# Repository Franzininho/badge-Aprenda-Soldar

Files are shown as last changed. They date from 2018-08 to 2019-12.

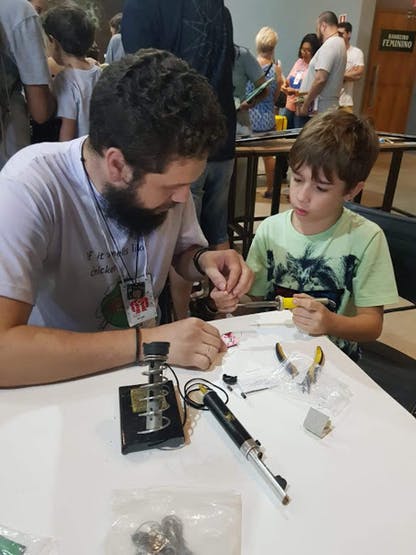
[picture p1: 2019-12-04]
img/05.jpg

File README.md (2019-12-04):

# Badge - Aprenda Soldar

O badge Aprenda Soldar foi desenvolvido para oficinas de solda onde os participantes dão os primeiros passos com o uso de ferramentas e no conhecimento dos componentes eletrônicos e circuito da placa. Com poucos componentes, esse badge permite que qualquer pessoa aprenda a soldar e se divertir.

O circuito escolhido para esse badge, foi o clássico multivibrador astável com trasistores.

A placa foi desenhada no [Kicad](https://kicad-pcb.org/) e os arquivos estão disponíveis no github. A placa possui duas camadas e necessita de metalização de furos para acabamento.

A seguir é apresentada a lista de materiais:

- 2 x Resistor 470k
- 2 x Resistor 470 Ohm
- 2 x transistor BC548
- 1x LED 3mm verde
- 1x LED 3mm amarelo
- 2 x Capacitor 10uF x 16V
- 1 x Suporte para bateria CR2032
- 1 x Bateria CR2032

Esse projeto foi um dos vencedores do [Contest badge Love](https://www.hackster.io/contests/BadgeLove) na categoria The Badge of Hope, promovido pelo [Hackster](https://www.hackster.io/fabiosouza/badge-aprenda-soldar-learn-to-solder-1f082d)

O projeto é open hardware e foi publicado sob a licença [Creative Commons Attribution Share Alike 4.0 International](https://github.com/Open-Badges/badge00/blob/master/LICENSE)

Esse projeto faz parte da família de placas Franzininho e foi desenvolvido por Fábio Souza, idealizador do projeto. Para mais detalhes acesse o site da [Franzininho](https://franzininho.com.br/)

Para adquirir placas e kits do badge Aprenda Soldar, entre em contato conosco: [contato@franzininho.com.br](contato@franzininho.com.br)

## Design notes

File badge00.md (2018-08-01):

## Badge00 - Aprenda Soldar

O Badge00 foi desenvolvido para oficinas de solda onde os participantes dão os primeiros passos com o uso de ferramentas e o conhecimento dos componentes.

O circuito escolhido para esse badge, foi o clássico multivibrador astável com trasistores.

### Placa



A placa foi desenhada no Kicad e os arquivos estão disponíveis no github. A placa foi desenhada em duas camadas e necessita de metalização de furos para acabamento.

### Circuito



O circuito..

### Lista de componentes

## Montagem

Para montagem, primeiramente é necessário preparar as ferramentas. Para a realização da soldagem do Badge00 você irá precisar das seguintes ferramentas e insumos:
- Ferro de solda 30 W
- Suporte para Ferro de solda
- Alicate de corte diagonal
- Estanho
- Sugador de solda (opcional)
- Suporte  para soldagem (terceira mão)(opcional)

Separe os componentes de forma organizada na sua bancada.

Verifique se o ferro de solda está aquecido e pronto para a soldagem.

Insira os resistores na placa:
- R1 - 470 R
- R2 - 47 K
- R3 - 47 K
- R4 - 470 R

Fique atento ao código de cores. Após inserir os resistores na placa, vire com cuidado para que os resistores não caiam e então, solde-os:

Com os resistores soldados, vamos soldar os transistores:

Q1 e Q2 = BC548(ou similar)

Encaixe os transistores em suas respectivas posições, vire a placa e solde-os:

Agora vamos soldar os capacitores eletrolíticos:

C1 e C2 = 10 uF x  25V

Para inserir os capacitores na placa é importante verificar a polaridade. Com os capacitores encaixados corretamente, vire a placa e sode os mesmos. Tome cuidado para que os mesmos fiquem apoiados a placas e não fiquem altos.

O próximo passo é a soldagem dos LEDs. Os LEDs dever ser soldados no lado do Robô. Encaixe os LEDs respeitando a polaridade. Vire a placa e solde os mesmos. Cuidados para que os LEDs não fiquem altos ou desalinhados.

Por ultimo, vamos soldar o suporte de baterias. Encaixe-o na placa e solde-o:

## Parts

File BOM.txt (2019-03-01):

Ref		Descrição									Quatidade
placa	Placa Badge00									1
Q1,Q2	Transistor BC548								2
C1, C2	Capacitor Eletrolítico 10uF x 25 V				2
R1,r4	Resistor 470R									2
R2,R3	Resistor 47K									2
BT1		Suporte de bateria CR2032						1
BT1		Bateria CR2032									1
LED1	Led Amarelo 3mm									1
LED2	LED Verde 3mm									1
S1		Chave HH - SS12D07								1

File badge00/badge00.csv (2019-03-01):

Id | Designator | Package | Quantity | Designation | Supplier and ref
1 | BT1 | CR2032_HOLDER | 1 | Battery_Cell
2 | R1,R4 | R_Axial_DIN0207_L6.3mm_D2.5mm_P10.16mm_Horizontal | 2 | 470R
3 | REF** | MountingHole_3.5mm | 1 | MountingHole_3.5mm
4 | C1,C2 | CP_Radial_D5.0mm_P2.50mm | 2 | 10uF
5 | D1,D2 | LED_D3.0mm | 2 | LED
6 | R2,R3 | R_Axial_DIN0207_L6.3mm_D2.5mm_P10.16mm_Horizontal | 2 | 47k
7 | Q1,Q2 | TO-92_Inline_Wide | 2 | BC548
8 | G*** | robot2_35x35 | 1 | LOGO
9 | G*** | logo-franzininho12_7 | 1 | LOGO
10 | SW1 | SW_HH_SS12D07-G4-2 | 1 | SW_SPDT
11 | REF*** | OSHW-Logo_7.5x8mm_SilkScreen | 1 | OSHW-Logo_7.5x8mm_SilkScreen
12 | REF*** | KiCad-Logo2_6mm_SilkScreen | 1 | KiCad-Logo2_6mm_SilkScreen

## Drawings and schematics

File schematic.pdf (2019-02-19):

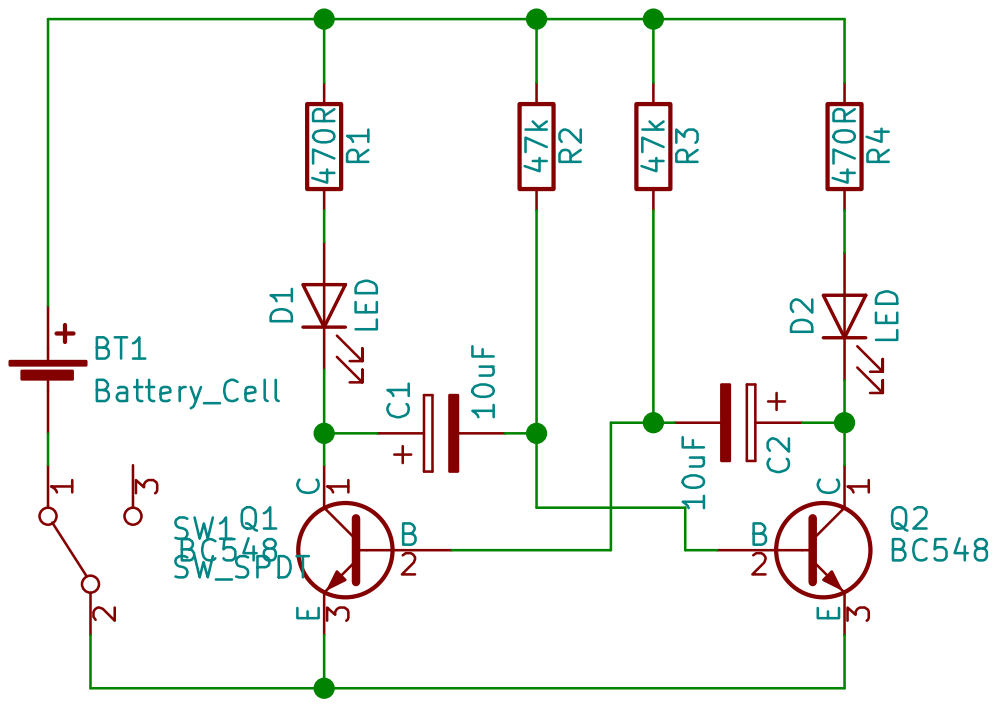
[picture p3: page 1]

File: badge00.sch Sheet: / Franzininho

Id: 1/1 Title: Badge - Aprenda Soldar

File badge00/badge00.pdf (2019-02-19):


File: badge00.sch Sheet: / Franzininho

Id: 1/1 Title: Badge - Aprenda Soldar

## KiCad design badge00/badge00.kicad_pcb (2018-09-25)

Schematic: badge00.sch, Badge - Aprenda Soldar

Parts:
BT1: Battery_Cell; CR2032_HOLDER
C1, C2: 10uF; CP_Radial_D5.0mm_P2.50mm
D1, D2: LED; LED_D3.0mm
Q1, Q2: BC548; TO-92_Inline_Wide
R1, R4: 470R; R_Axial_DIN0207_L6.3mm_D2.5mm_P10.16mm_Horizontal
R2, R3: 47k; R_Axial_DIN0207_L6.3mm_D2.5mm_P10.16mm_Horizontal
SW1: SW_SPDT; SW_HH_SS12D07-G4-2

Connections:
unnamed: BT1.1, R1.1, R2.1, R3.1, R4.1
unnamed: BT1.2, SW1.1
unnamed: C1.1, D1.1, Q1.1 (C)
unnamed: C1.2, Q2.2 (B), R2.2
unnamed: C2.1, D2.1, Q2.1 (C)
unnamed: C2.2, Q1.2 (B), R3.2
unnamed: D1.2, R1.2
unnamed: D2.2, R4.2
unnamed: Q1.3 (E), Q2.3 (E), SW1.2

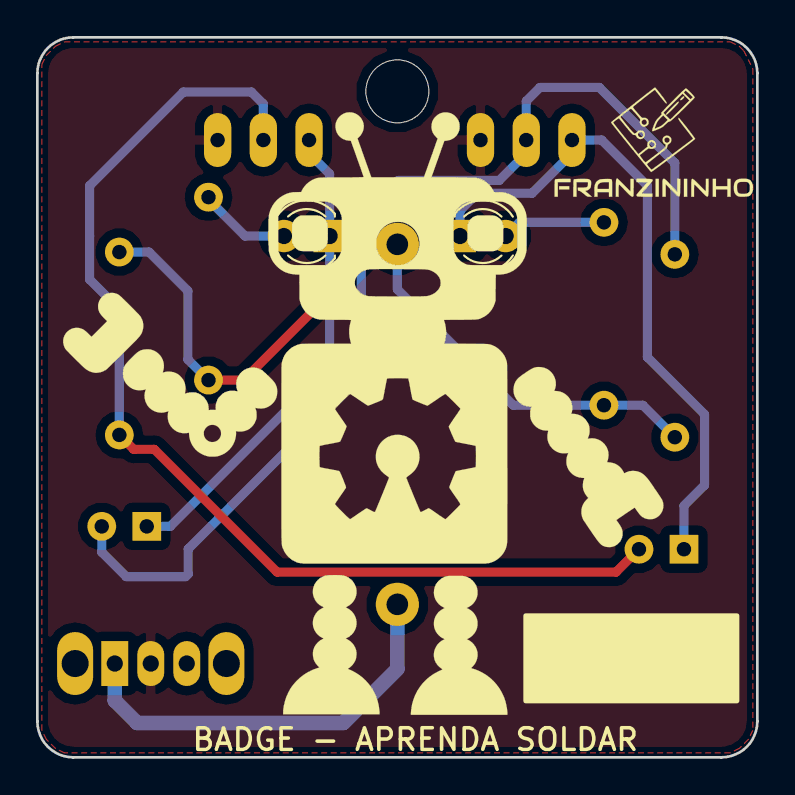
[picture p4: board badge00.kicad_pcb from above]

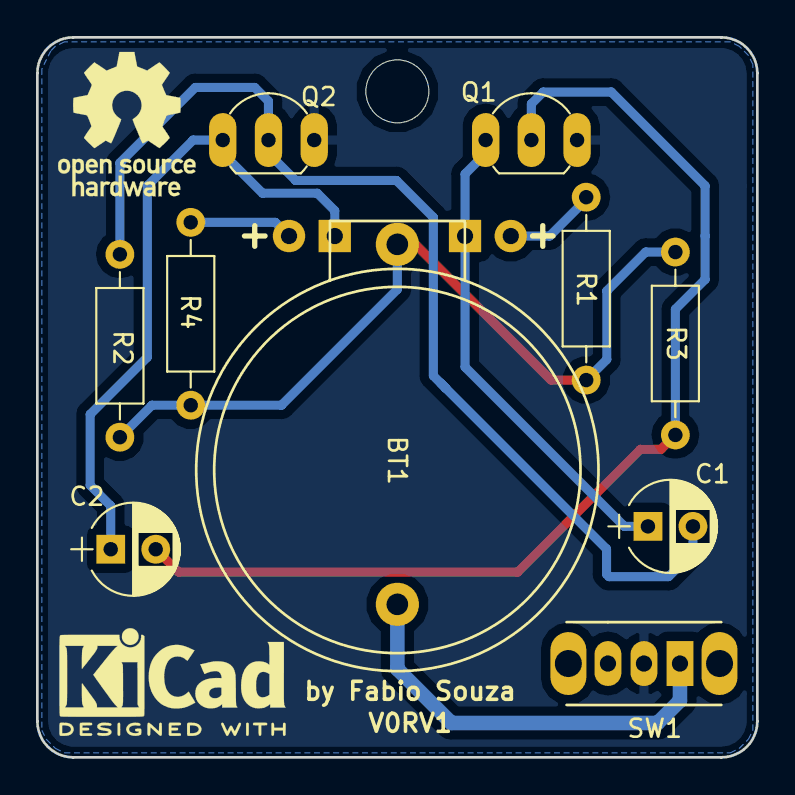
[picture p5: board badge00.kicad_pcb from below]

Board: 2 copper layers, 40.0 x 40.0 mm, 12 parts (10 on the bottom side), 9 nets.

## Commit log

2018-07-06 kicad files
    [badge00.kicad_pcb, badge00.sch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]
2018-07-31 upadate schematic
    [badge00.sch]
2018-08-01 documentação
    [badge00-2018-08-01-11-49-02.sch]
2019-03-01 BOM txt
2019-03-01 Move BOM
2019-12-04 Ajuste de arquivos na pasta e Readme
2019-12-04 correção de erro ortográfico
2019-12-04 Adicionada pasta com fotos e imagens para documentação
2019-12-04 Ajuste de links e e-mail
